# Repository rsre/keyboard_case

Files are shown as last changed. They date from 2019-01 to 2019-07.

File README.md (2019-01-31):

# Design exploration to make a case for ALPS I2KC273A

Some time ago a friend gave me this barebones keyboard with Alps switches. They seem to be Alps SKCC Cream. It has some very nice old school spheric keycaps. The keyboard consists of a steel plane where the switches are mounted and a PCB that connects them. I decided to create a case for it so I can use it.

All the designs are made using [OpenSCAD](http://openscad.org).

## Iterations

First I modelled the keyboard so I could design around it.

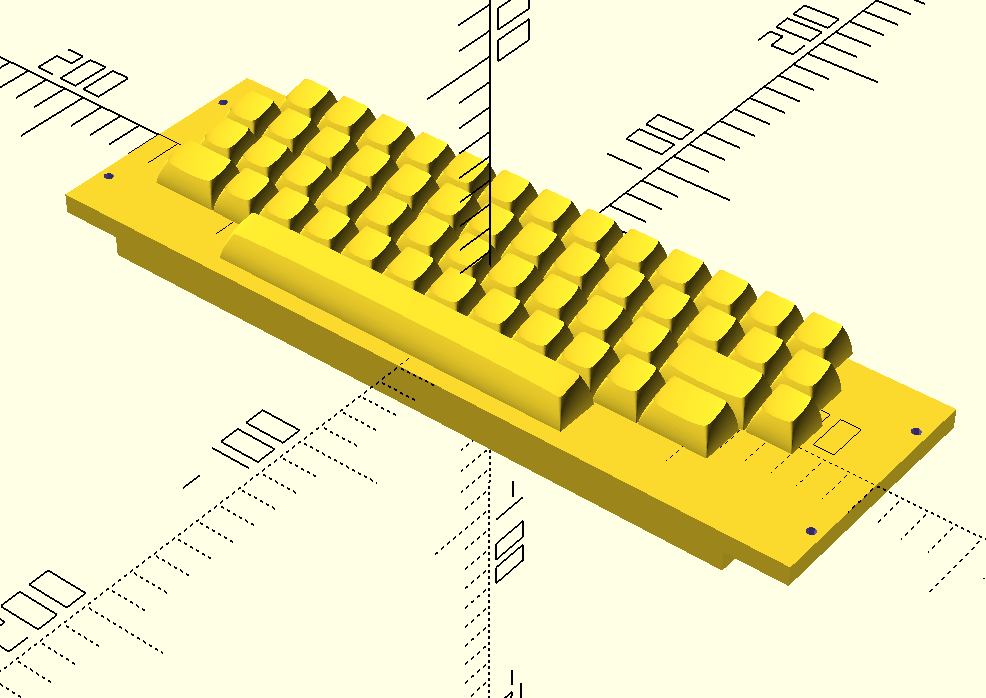
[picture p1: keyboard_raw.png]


On my first try I began by designing a case loosely based on the IBM Pingmaster and the IBM Model M. I didn't like how bulky it was coming out and the lack of design features didn't allow to make it feel slimer so I abandoned the first design.

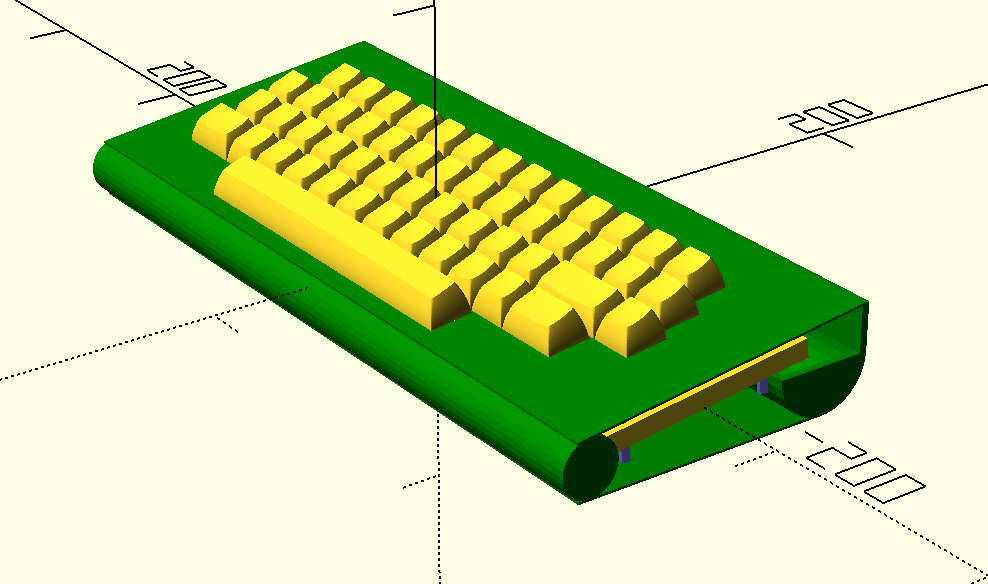
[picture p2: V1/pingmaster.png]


The second iteration was also based on a classic: the kishaver. This time I decided to try another approach to OpenSCAD design. The idea was to design the outer shell first and then hollow it accordingly. However, once I had the outside done I didn't really like the way it looked. Kishaver looks cool when your keyboard layout fills the whole well, a nice, squared layout. With my layout it looked too spare.

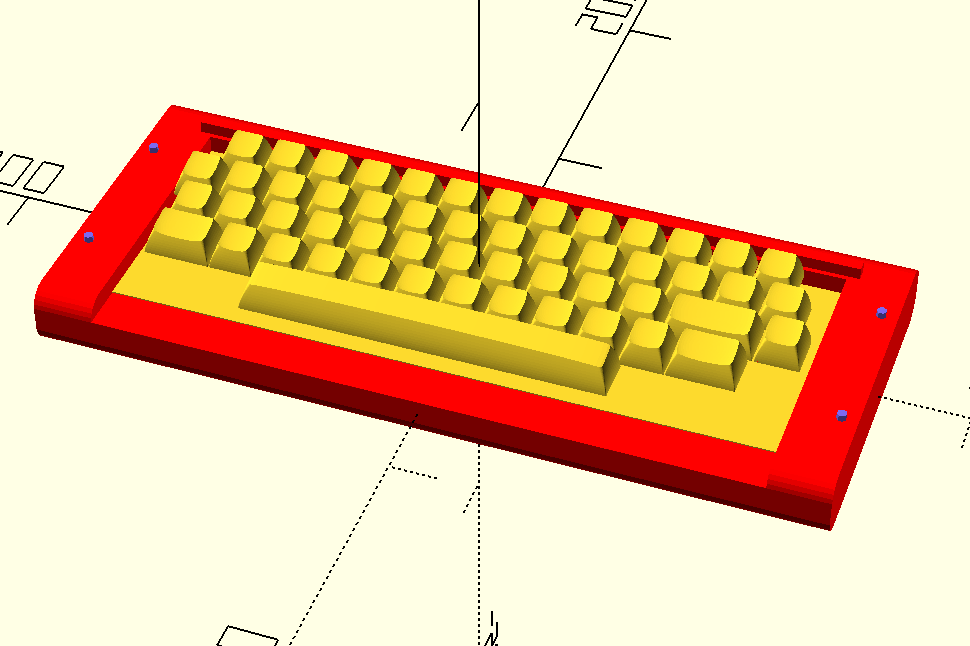
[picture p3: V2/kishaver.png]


Looking for some inspiration I came across a Cherry G80-3000 inspired GH60 case. I quite liked the design so I setted to try to imitate it. I liked that it looked kind of retro but also that it had some design elements that could help me make the complete thing more sleek and slim. I designed the outer case with a few custom modifications like the top bar over the keys, I love having a place to rest my pen there. I proceded to hollow it out and then added a lip between the two parts and screw holes so it can be fastened together. I also added a place to add a USB port like [this](https://es.aliexpress.com/item/2017-New-Arrival-Black-Printer-Panel-Mount-Cable-Screw-Mini-USB-5-Pin-Male-to-USB/32831695483.html) and some branding. I don't have the proper measures for the USB port and I don't know if I'll even be able to fit it in the final design without some modding, We'll see.

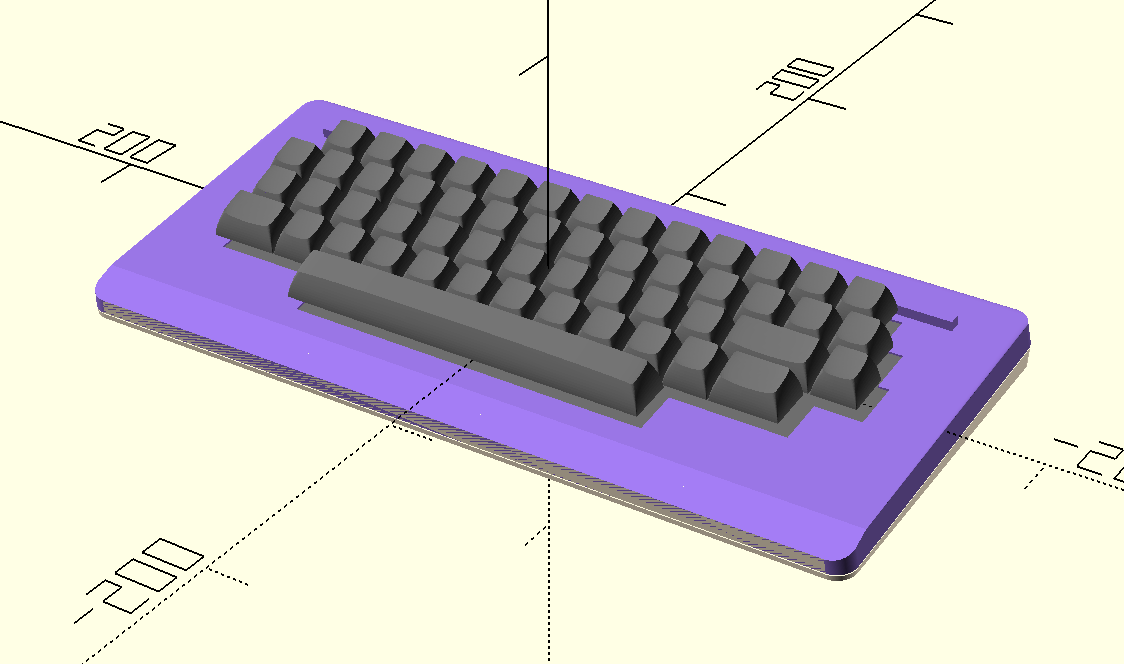
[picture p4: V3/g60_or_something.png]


I have decided to print this diagonally and vertical in the sort axis in my printer because I can only print 300x200mm. I still have to do do some test prints at scale, check if everything fits, correct mistakes, etc.

## Electronics and firmware

In testing I was using an arduino UNO with some code I found online. In the "final" version I'll probably use the TMK or QMK firmware with an arduino nano or something along the lines.

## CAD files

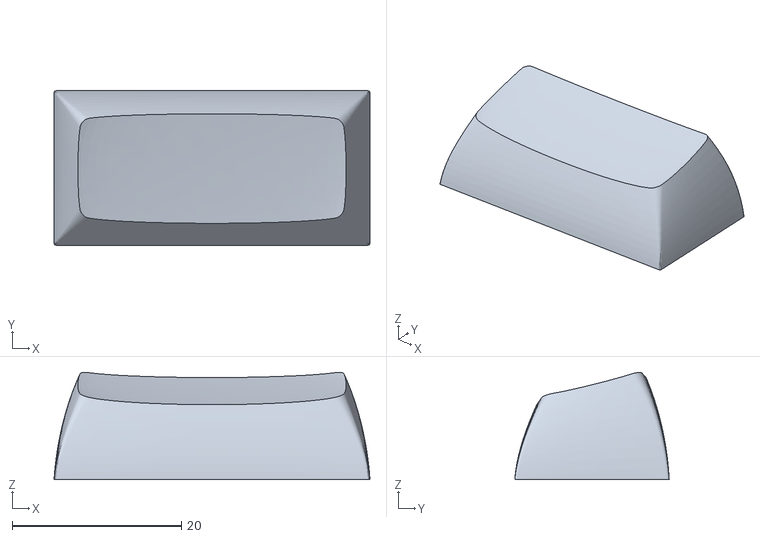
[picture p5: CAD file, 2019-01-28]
custom_keycaps/length-2.stl
37.3 x 18.2 x 12.7

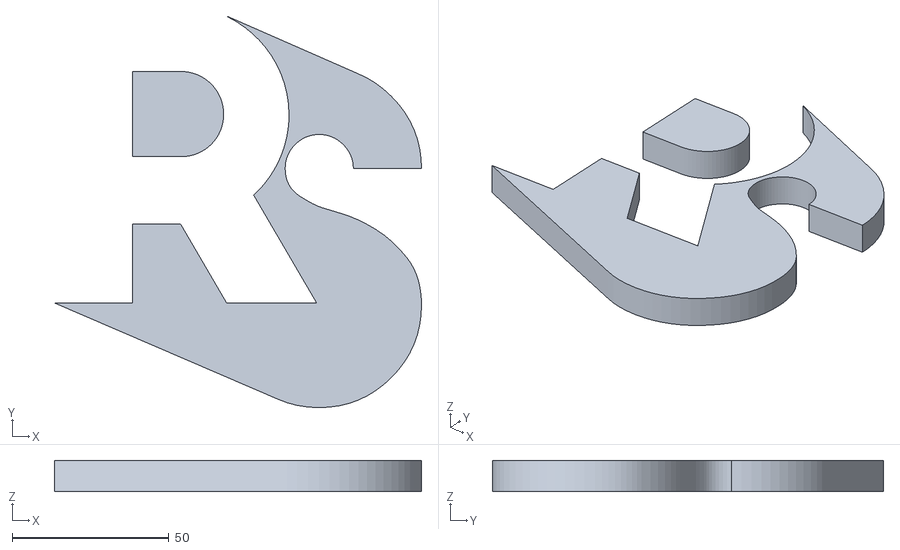
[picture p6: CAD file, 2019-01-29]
RS.stl
117.2 x 125.0 x 10.0

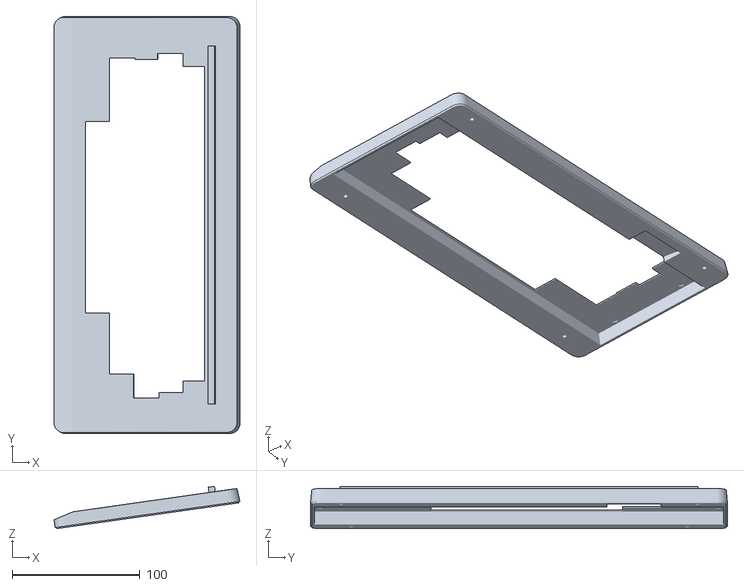
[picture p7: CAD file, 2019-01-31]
V3/keyboard_case_v3_top.stl
145.5 x 326.2 x 33.1

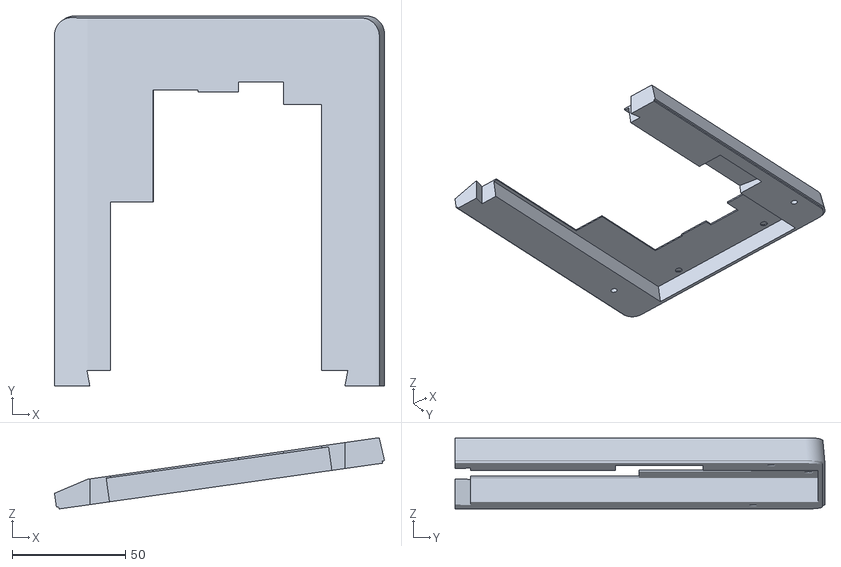
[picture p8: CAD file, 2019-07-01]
V3/v3_cut/keyboard_case_v3_top_left.stl
145.5 x 163.1 x 31.3

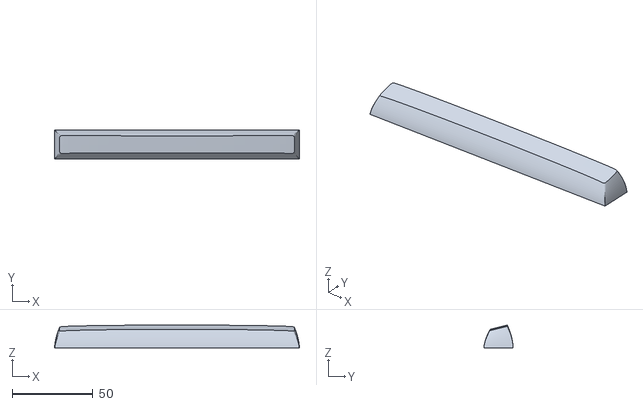
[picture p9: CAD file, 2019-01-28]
custom_keycaps/spacebar.stl
151.6 x 18.2 x 14.2

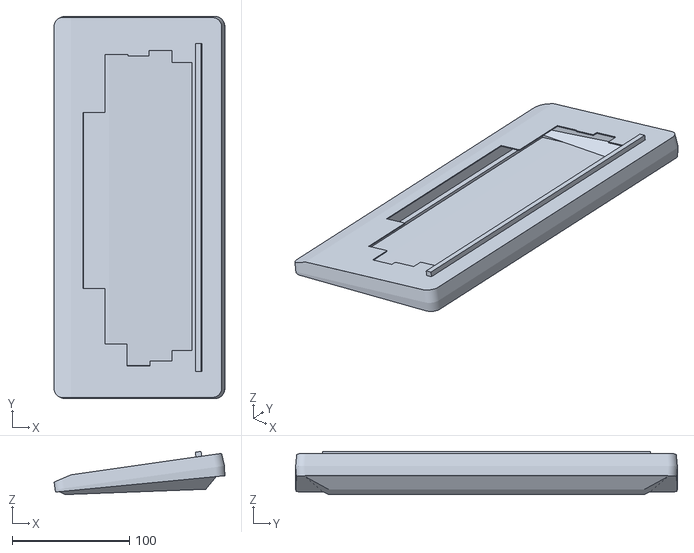
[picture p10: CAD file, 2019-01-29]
V3/keyboard_case_v3.stl
146.0 x 326.2 x 36.9

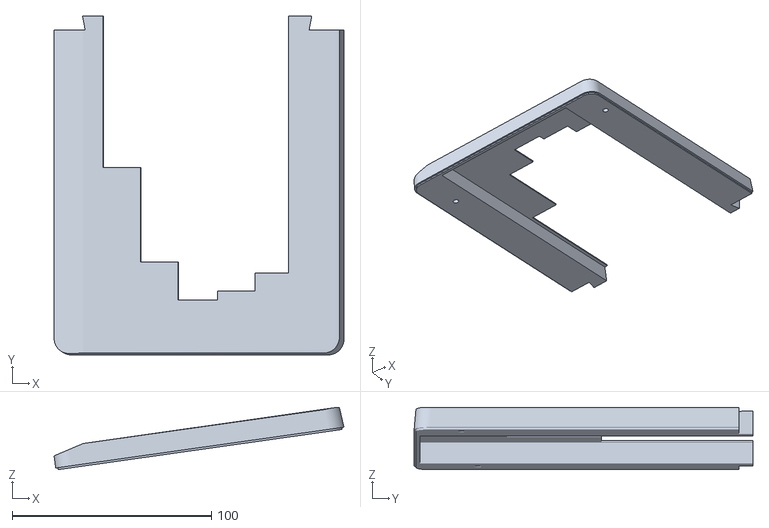
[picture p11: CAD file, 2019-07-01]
V3/v3_cut/keyboard_case_v3_top_right.stl
145.5 x 170.0 x 31.3

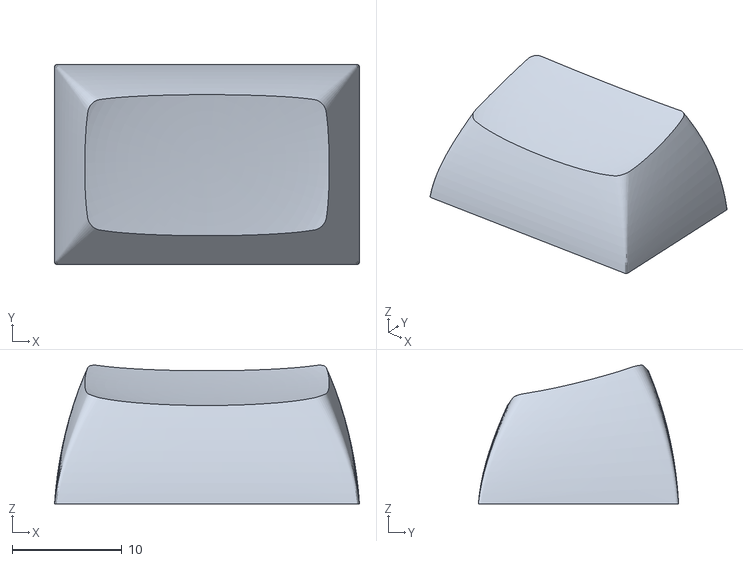
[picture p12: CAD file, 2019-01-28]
custom_keycaps/length-1.5.stl
27.8 x 18.2 x 12.6

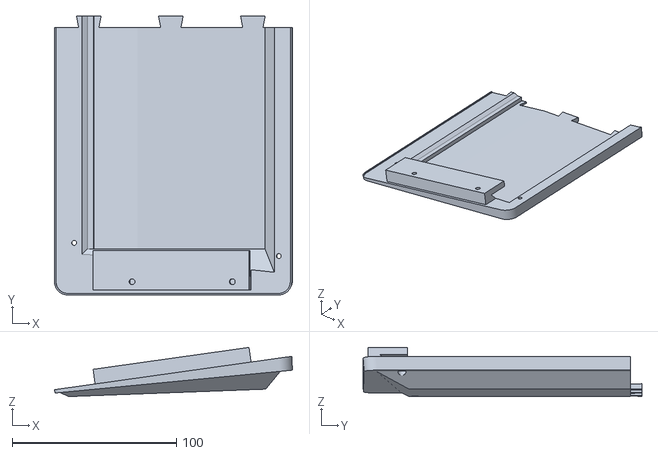
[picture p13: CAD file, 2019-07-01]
V3/v3_cut/keyboard_case_v3_bot_right.stl
145.1 x 169.9 x 30.0

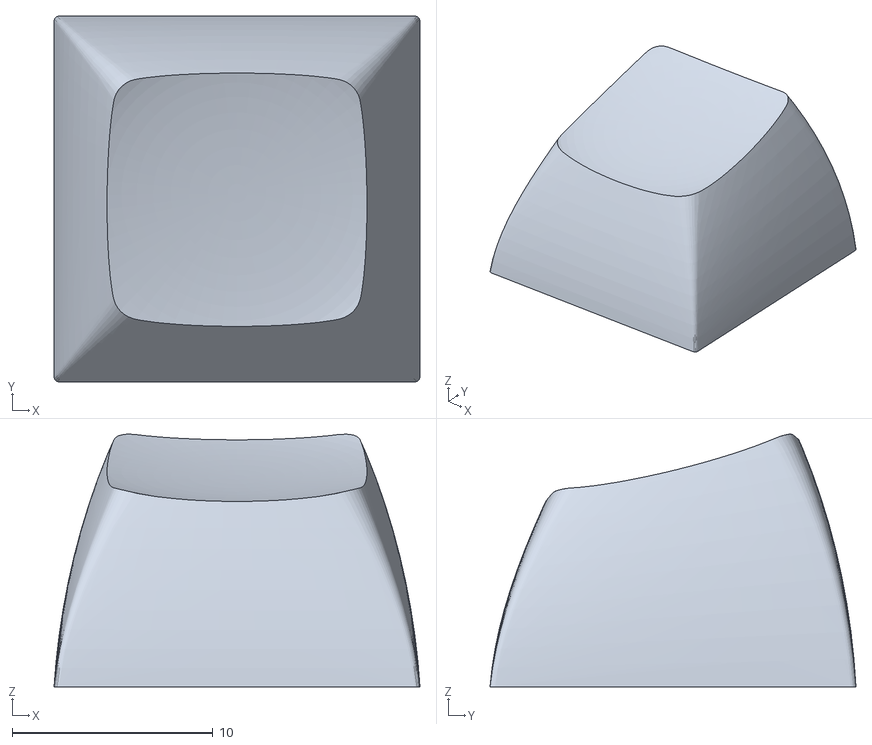
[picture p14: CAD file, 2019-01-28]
custom_keycaps/length-1.stl
18.2 x 18.2 x 12.6

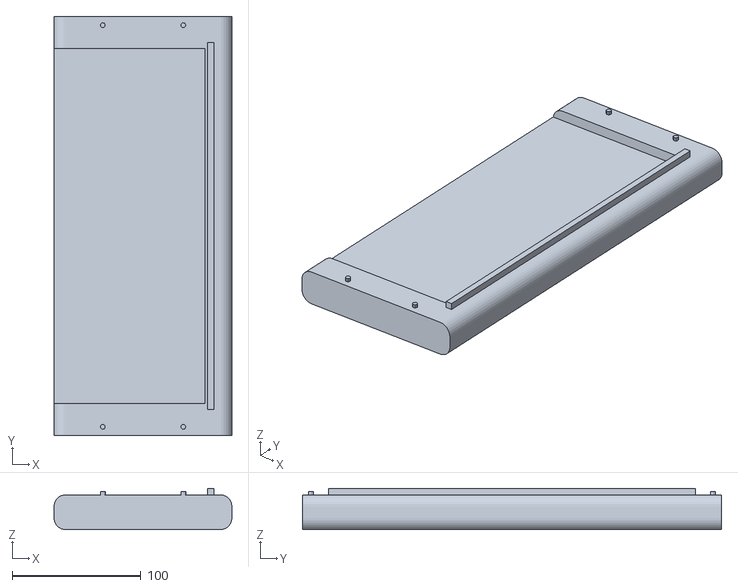
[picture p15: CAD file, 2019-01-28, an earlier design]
V2/keyboard_case_kishaver.stl
137.9 x 325.0 x 32.0

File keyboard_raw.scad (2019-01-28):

mounting_hole_A = 62.5;
mounting_hole_B = 311.5;

keyboard();

module keyboard(){
    keyboard_thick_side = 8;
    keyboard_thick_centre = 15;
    length_centre = 270;
    length_total = 270+25+25;
    width = 99;
    
    translate([0,0,-16]){
        translate([0,0,23])keycaps();
        difference(){
            union(){
                translate([-width/2, -length_centre/2, 0])cube([width, length_centre, keyboard_thick_centre]);
                translate([-width/2, -length_total/2, keyboard_thick_side])cube([width, length_total, keyboard_thick_side]);
            }
        mounting_screws();
        }
    }
}

module mounting_screws(){
    height = 16.2;
    diameter = 4;
    color("MediumSlateBlue"){
        translate([mounting_hole_A/2, mounting_hole_B/2, 0])cylinder(h=height,d=diameter);
        translate([-mounting_hole_A/2, mounting_hole_B/2, 0])cylinder(h=height,d=diameter);
        translate([mounting_hole_A/2, -mounting_hole_B/2, 0])cylinder(h=height,d=diameter);
        translate([-mounting_hole_A/2, -mounting_hole_B/2, 0])cylinder(h=height,d=diameter);
    }
}

module key(){
    rotate([0,0,270])import("./custom_keycaps/length-1.stl");
}

module key_and_half(){
    rotate([0,0,270])import("./custom_keycaps/length-1.5.stl");
}

module key_double(){
    rotate([0,0,270])import("./custom_keycaps/length-2.stl");
}

module spacebar(){
    rotate([0,0,270])import("./custom_keycaps/spacebar.stl");
}

module keycaps(){
    //translate([0,0,-7])cube([20,20,20]);//spacer
    //row 1
    translate([-40,7,0])spacebar();
    //row 2
    translate([-21,-100,0]){
        key_and_half();
        translate([0,23.5,0])for(i = [0 : 9]){
            translate([0,19*i,0])key();
        }
        translate([0,28+19*10,0])key_and_half();
    }
    //row 3
    translate([-2,-125,0]){
        translate([0,0,0])key();
        translate([0,28.5,0])key_double();
        translate([0,57,0])for(i = [0 : 10]){
            translate([0,19*i,0])key();
        }
    }
    //row 4
    translate([17,-120,0])for(i = [0 : 13]){
        translate([0,19*i,0])key();
    }
    //row 5
    translate([36,-112,0])for(i = [0 : 12]){
        translate([0,19*i,0])key();
    }
}

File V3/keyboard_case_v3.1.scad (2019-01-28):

//mounting holes separation 62.5mm 311.5mm
//mounting holes to border 12.5mm to top 24mm to bottom
//$fn = 255;

mounting_hole_A = 62.5;
mounting_hole_B = 311.5;
keyboard_length = 318;
keyboard_width = 98.50;

main_angle = 8;
bottom_angle = 2.5;

case_width = 130;
case_length = 310;
corner_inclination = 5;

top_case_height = 10;
bottom_case_height = 8;

total_case_height = 20;


complete_case();
translate([0,0,-15.5])rotate([0,-(main_angle-bottom_angle),0])base3();

module complete_case(){
    union(){
        rotate([0,-main_angle,0]){
            keyboard();
            #color("MediumPurple")top_case();
            #color("red")bottom_case();
        }
    }
}

module top_case(){
    translate([0,0,-top_case_height])difference(){
        hull(){
            translate([case_width/2,case_length/2,top_case_height/2-4])rotate([corner_inclination,-corner_inclination,0])cylinder(h=top_case_height+8, r = 8, center=true);
            translate([-case_width/2,case_length/2,top_case_height/2])cylinder(h=top_case_height,r = 8, center=true);
            translate([case_width/2,-case_length/2,top_case_height/2-4])rotate([-corner_inclination,-corner_inclination,0])cylinder(h=top_case_height+8,r = 8, center=true);
            translate([-case_width/2,-case_length/2,top_case_height/2])cylinder(h=top_case_height,r = 8, center=true);
        }
        translate([-case_width/2-25,-(case_length+30)/2,top_case_height/2-3])rotate([0,-15,0])cube([40,case_length+30,20]);
        translate([-(case_width+30)/2,-(case_length+30)/2,-10])cube([case_width+30,case_length+30,10]);
    }
}

module bottom_case(){
    translate([0,0,-(bottom_case_height+top_case_height)])difference(){
        hull(){
            translate([case_width/2,case_length/2,bottom_case_height/2+4])rotate([-corner_inclination,corner_inclination,0])cylinder(h=bottom_case_height+8,r = 8, center=true);
            translate([-case_width/2,case_length/2,bottom_case_height/2])cylinder(h=bottom_case_height,r = 8, center=true);
            translate([case_width/2,-case_length/2,bottom_case_height/2+4])rotate([corner_inclination,corner_inclination,0])cylinder(h=bottom_case_height+8,r = 8, center=true);
            translate([-case_width/2,-case_length/2,bottom_case_height/2])cylinder(h=bottom_case_height,r = 8, center=true);
        }    
    	translate([-(case_width+30)/2,-(case_length+30)/2,bottom_case_height])cube([case_width+30,case_length+30,10]);
	    rotate([0,0,0])translate([(case_width+18)/2,(case_length+30)/2,-10.5])rotate([0,-bottom_angle,180])cube([case_width+18,case_length+30,10]);
    }
}

module base(){
    A = case_width/2;
    B = case_length/2;
    base_taper = 20;
    back_taper = 10;
    height = 10; //old value was 10, should be calc according to bottom_angle and main_angle
    color("green")polyhedron(
        points=[
            [A,B,0],[A,-B,0],[-A,-(B-base_taper),0],[-A,B-base_taper,0],//base
            [A-back_taper,-(B-base_taper),-height],[A-back_taper,B-base_taper,-height]
        ], 
        faces =[
            [0,3,2,1],//base
            [0,1,4,5],//back
            [0,5,3],//side
            [1,2,4],//side
            [2,3,5,4]//top
        ]
    );
}

module base2(){
    A = case_width/2;
    B = case_length/2;
    base_taper = 20;
    back_taper = 10;
    front_height = 3;
    height = 10; //old value was 10, should be calc according to bottom_angle and main_angle
    color("green")polyhedron(
        points=[
            [A,B,0],[A,-B,0],[-A,-(B-base_taper),0],[-A,B-base_taper,0],//base
            [A-back_taper,-(B-base_taper),-height],[A-back_taper,B-base_taper,-height],
            [-A,B-base_taper,-front_height],[-A,-(B-base_taper),-front_height]
        ], 
        faces =[
            [0,3,2,1],//base
            [0,1,4,5],//back
            [0,5,6,3],//side
            [1,2,7,4],//side
            [2,3,6,7],//front
            [7,6,5,4]//top
        ]
    );
}

module base3(){
    A = case_width/2;
    B = case_length/2;
    base_taper = 20;
    base_taper2 = 5;
    back_taper = 10;
    front_height = 3;
    height = 10; //old value was 10, should be calc according to bottom_angle and main_angle
    color("green")polyhedron(
        points=[
            [A,B,0],[A,-B,0],[-(A+base_taper2),-(B-base_taper+base_taper2),0],[-(A+base_taper2),B-base_taper+base_taper2,0],//base
            [A-back_taper,-(B-base_taper),-height],[A-back_taper,B-base_taper,-height],
            [-A,B-base_taper,-front_height],[-A,-(B-base_taper),-front_height]
        ], 
        faces =[
            [0,3,2,1],//base
            [0,1,4,5],//back
            [0,5,6,3],//side
            [1,2,7,4],//side
            [2,3,6,7],//front
            [7,6,5,4]//top
        ]
    );
}

module keyboard(){
    keyboard_thick_side = 8;
    keyboard_thick_centre = 15;
    length_centre = 270;
    length_total = 270+25+25;
    width = 99;
    
    translate([0,0,-16]){
        mounting_screws();
        translate([0,0,23])keycaps();
        //keycaps_bulk();
        translate([-width/2, -length_centre/2, 0])cube([width, length_centre, keyboard_thick_centre]);
        translate([-width/2, -length_total/2, keyboard_thick_side])cube([width, length_total, keyboard_thick_side]);
    }
}

module mounting_screws(){
    height = 16.2;
    diameter = 4;
    color("MediumSlateBlue"){
        translate([mounting_hole_A/2, mounting_hole_B/2, 0])cylinder(h=height,d=diameter);
        translate([-mounting_hole_A/2, mounting_hole_B/2, 0])cylinder(h=height,d=diameter);
        translate([mounting_hole_A/2, -mounting_hole_B/2, 0])cylinder(h=height,d=diameter);
        translate([-mounting_hole_A/2, -mounting_hole_B/2, 0])cylinder(h=height,d=diameter);
    }
}

module key(){
    rotate([0,0,270])import("./custom_keycaps/length-1.stl");
}

module key_and_half(){
    rotate([0,0,270])import("./custom_keycaps/length-1.5.stl");
}

module key_double(){
    rotate([0,0,270])import("./custom_keycaps/length-2.stl");
}

module spacebar(){
    rotate([0,0,270])import("./custom_keycaps/spacebar.stl");
}

module keycaps(){
    //translate([0,0,-7])cube([20,20,20]);//spacer
    //row 1
    translate([-40,7,0])spacebar();
    //row 2
    translate([-21,-100,0]){
        key_and_half();
        translate([0,23.5,0])for(i = [0 : 9]){
            translate([0,19*i,0])key();
        }
        translate([0,28+19*10,0])key_and_half();
    }
    //row 3
    translate([-2,-125,0]){
        translate([0,0,0])key();
        translate([0,28.5,0])key_double();
        translate([0,57,0])for(i = [0 : 10]){
            translate([0,19*i,0])key();
        }
    }
    //row 4
    translate([17,-120,0])for(i = [0 : 13]){
        translate([0,19*i,0])key();
    }
    //row 5
    translate([36,-112,0])for(i = [0 : 12]){
        translate([0,19*i,0])key();
    }
}

module keycaps_bulk(){
    d_to_top = 3;
    d_to_bot = 1;
    1U = 18;
    1point5U = 28;
    2U = 36;
    spacebar = 150;
    spacing = 1;
    row_1 = 13*1U + 12*spacing;
    row_2 = 14*1U + 13*spacing;
    row_3 = 12*1U + 2U + 13*spacing;
    row_4 = 2*1point5U + 10*1U + 11*spacing;
    color("Green"){
        translate([keyboard_width/2-d_to_top-1U,-keyboard_length/2 + 38,0])cube([1U,row_1,18]);
        translate([keyboard_width/2-d_to_top-2*1U-spacing,-keyboard_length/2 + 29,0])cube([1U,row_2,18]);
        translate([keyboard_width/2-d_to_top-3*1U-2*spacing,-keyboard_length/2 + 24.5,0])cube([1U,row_3,18]);
        translate([keyboard_width/2-d_to_top-4*1U-3*spacing,-keyboard_length/2 + 43.5,0])cube([1U,row_4,18]);
        translate([keyboard_width/2-d_to_top-5*1U-4*spacing,-keyboard_length/2 + 91,0])cube([1U,spacebar,18]);
    }
}

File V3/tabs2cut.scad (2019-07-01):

cutter(0);
#cutter(1);

module cutter(side = 0){
    if (side == 0){
        difference(){
            translate([0,200.01,0])cube([200,400,50], center = true);
            translate([0,-200,0])cube([200,400,50], center = true);
            tab(0);
            tab(-50);
            tab(50);
        }
    } else {
        translate([0,-200,0])cube([200,400,50], center = true);
        tab(0);
        tab(-50);
        tab(50);
    }
}

module tab(distance){
    tab_deep = 7;
    difference(){
        translate([distance,tab_deep-0.1,0])scale([1,1,9])rotate([90,0,0])linear_extrude(height = tab_deep, scale = 14/17) square(15, center = true);
        translate([0,0,-50.001])cube([210,210,50], center = true);
        translate([0,0,50.001])cube([210,210,50], center = true);
    }
}

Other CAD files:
V1/keyboard_case.scad
V2/keyboard_case_kishaver.scad
V3/keyboard_case_v3.scad

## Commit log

2019-01-28 Removed old files
    [keyboard_case_v3.0.scad, keyboard_case_v3.0.stl, keyboard_case_v3.1.stl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]
2019-01-28 Simplifed sides
    [keyboard_case_v3.scad, keyboard_case_v3.stl]
2019-01-28 Switches cutout
    [keyboard_case_kishaver.scad, keyboard_case_v3.scad]
2019-01-28 Fixed polyhedron
    [keyboard_case_v3.scad]
2019-01-29 Added keyboard support
    [keyboard_case_v3.scad, keyboard_case_v3.stl]
2019-01-29 Added screw holes and top and bottom interlock
    [keyboard_case_v3.scad]
2019-01-29 Added branding
    [RS.stl, keyboard_case_v3.scad]
2019-01-30 Added USB A mounting hole
    Added USB A mounting hole to use with https://es.aliexpress.com/item/2017-New-Arrival-Black-Printer-Panel-Mount-Cable-Screw-Mini-USB-5-Pin-Male-to-USB/32831695483.html still missing proper measurements.
    [keyboard_case_v3.scad]
2019-01-31 Updated USB a little, fixed bottom hollowing for sturdiness, fixed mounting studs in top case.
    [keyboard_case_v3.scad, keyboard_case_v3_top.stl]
2019-02-05 Removed unneeded parameter
    [keyboard_case_v3.scad]
2019-07-01 Cuts case in half, fixes sizes.
    [keyboard_case_v3.scad, keyboard_case_v3_bot_right.stl, keyboard_case_v3_top_left.stl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]
